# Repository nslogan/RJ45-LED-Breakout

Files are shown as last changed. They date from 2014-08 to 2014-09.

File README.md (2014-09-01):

# RJ45-LED-Breakout

## Description

Simple breakout board for an RJ45 with LEDs. Has two 0805 resistor pads tied to Vin with pins for LED1/2-. Has solder pads for both shield legs to optionally tie to ground. Intended for use with Amphenol RJHSE-548x series. You can find [this project on GitHub](https://github.com/nslogan/RJ45-LED-Breakout). Fits breadboard well with headers 0.9" apart.

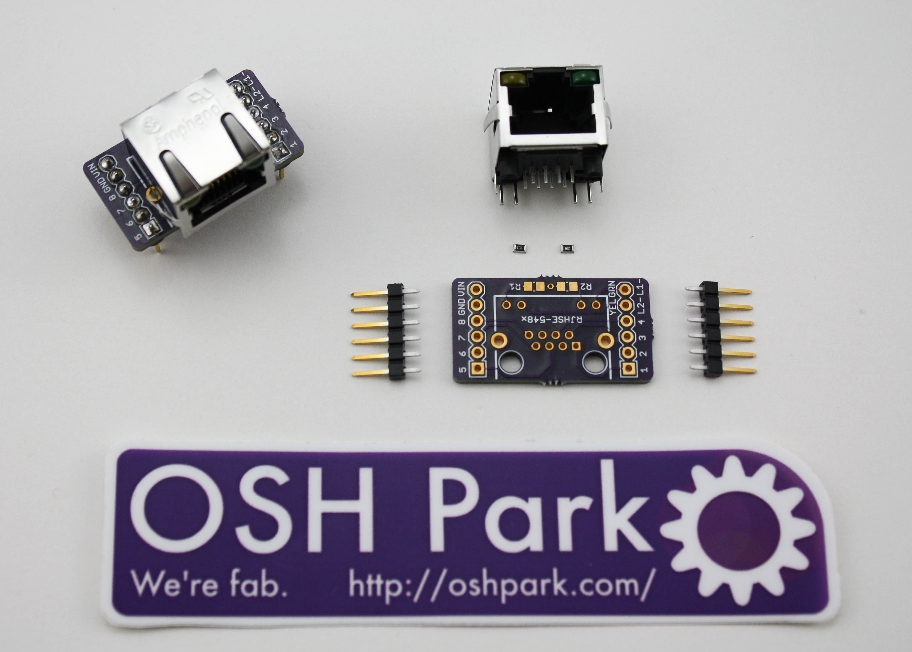
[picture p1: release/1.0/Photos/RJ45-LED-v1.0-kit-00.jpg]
RJ45-LED-Breakout Kit


## Production

The board measured 0.65x1.20in (17x30mm) and was designed for production at [OSH Park](https://www.oshpark.com/). The OSHPark DRU is located in the `res/` folder.

The boards can be purchased [here](https://www.oshpark.com/shared_projects/6Iadx5r2) @ $3.90 for three.

## Parts

All parts on this board are from the [LoganSmith-Eagle-Library](https://github.com/nslogan/LoganSmith-Eagle-Library) available on GitHub (work in progress).

The BOM is located in the release folder, all parts are sourced from Digi-Key.

## Project Structure

This project adheres to this structure:

	[ProjectName]
		README.md
		[release]
			[Major.Minor]
				ProjectName_BOM_Major.Minor.xls or ProjectName_BOM_BOM_Major.Minor.csv
				ProjectName_schematic_Major.Minor.pdf
				ProjectName_board-<top/mid#/bottom>_Major.Minor.png
				ProjectName_Major.Minor.sch
				ProjectName_Major.Minor.brd
				[Gerbers]
					...
			...
		[src]
			[Major.0]
				BoardName.sch
				BoardName.brd
				BOM.xls or BOM.csv
			[Major+1.0]
				...
			...
		[lib]
			...
		[res]
			Manufacturer.dru
			Manufacturer.cam

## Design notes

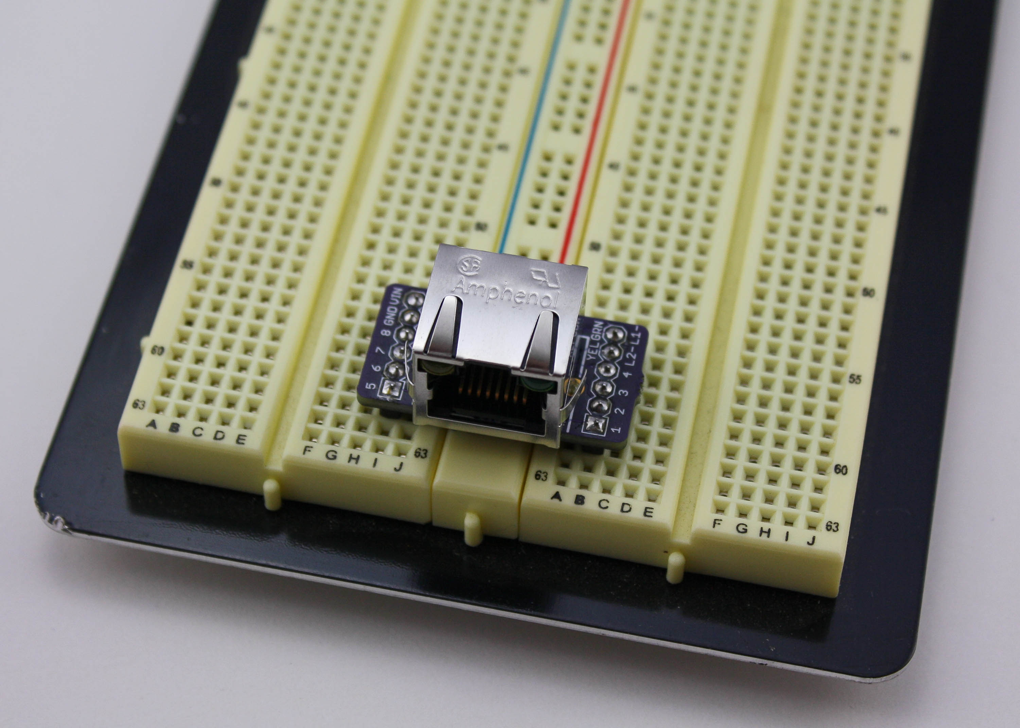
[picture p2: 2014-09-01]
release/1.0/Photos/RJ45-LED-v1.0-on-board-00.jpg

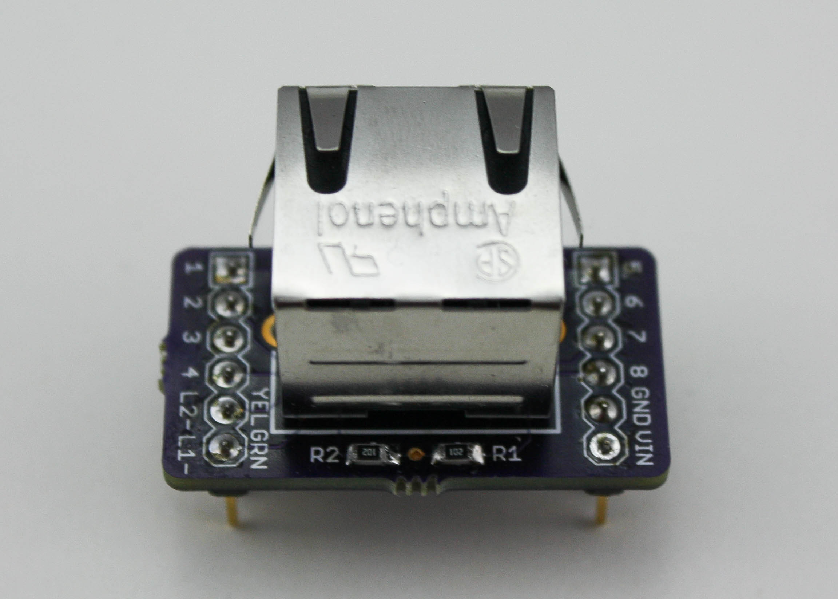
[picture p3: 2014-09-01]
release/1.0/Photos/RJ45-LED-v1.0-pop-top-00.jpg

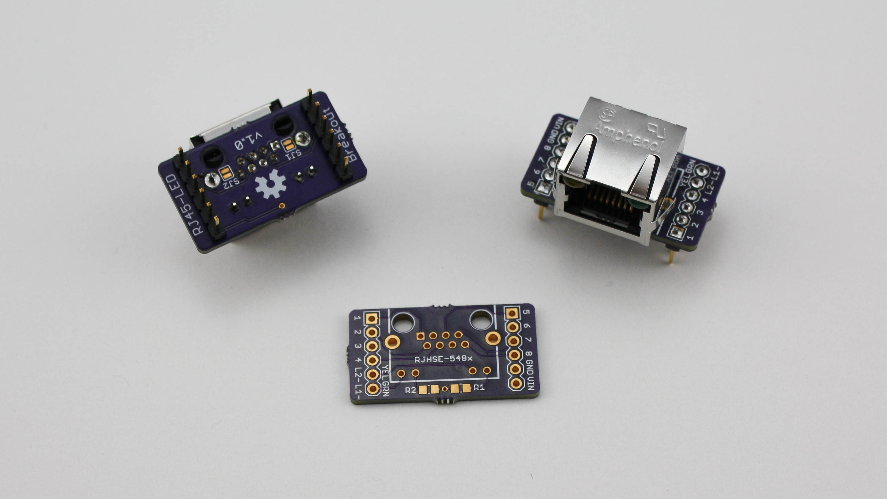
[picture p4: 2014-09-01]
release/1.0/Photos/RJ45-LED-v1.0-2pop-1upop-00.jpg

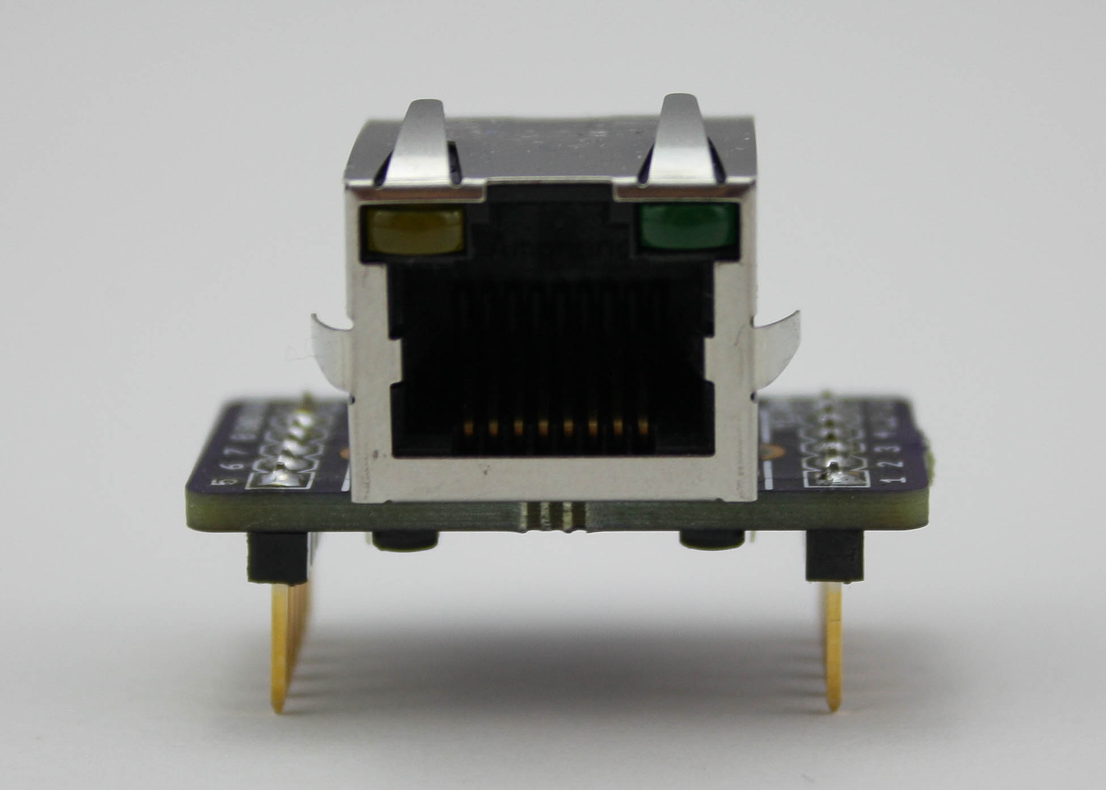
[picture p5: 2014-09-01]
release/1.0/Photos/RJ45-LED-v1.0-pop-front.jpg

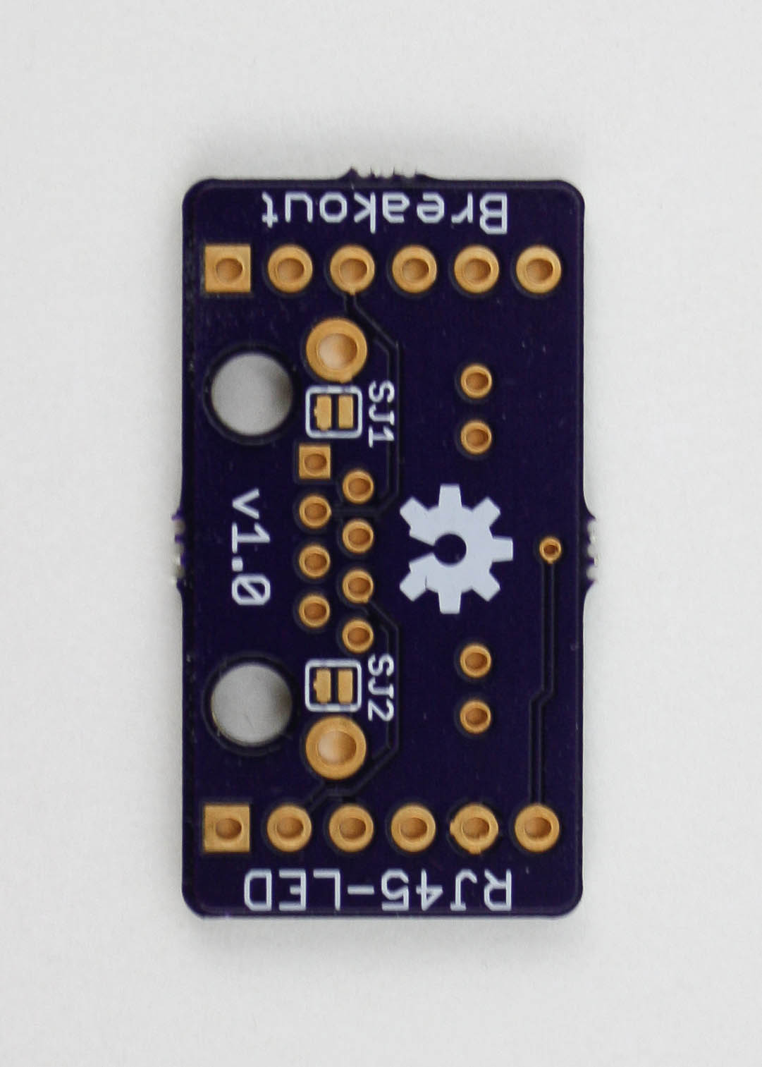
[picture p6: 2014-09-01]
release/1.0/Photos/RJ45-LED-v1.0-bottom.jpg

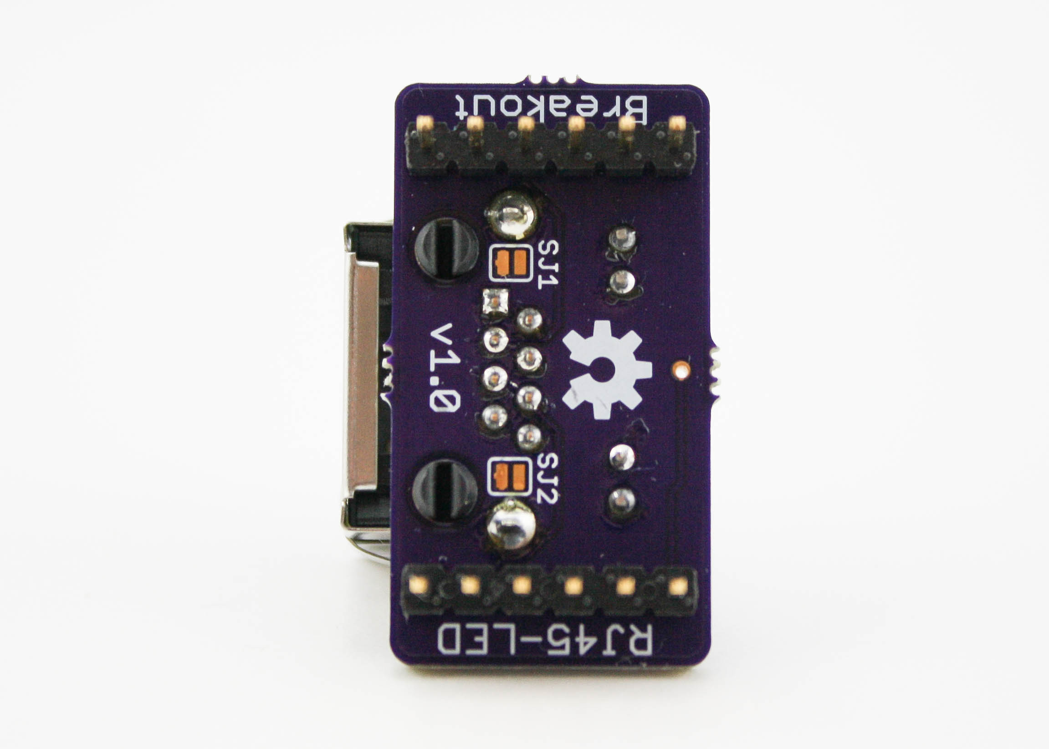
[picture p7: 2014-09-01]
release/1.0/Photos/RJ45-LED-v1.0-pop-bottom.jpg

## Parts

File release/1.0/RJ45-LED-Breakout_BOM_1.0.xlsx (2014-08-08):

Part | QTY | Package | Description | DIGIKEY_OC | MFR | MPN | TEMP_RANGE | THICK | VALUE
J1 | 1 | RJ45-RJHSE | Shielded CAT5 RJ45 90 w/ LED and board lock | RJHSE-5481-ND | Amphenol Commercial Products | RJHSE-5481 | -55C to 85C | 0.530in | RJ45
J2,J3 | 2 | 1x6 | 1x8 Headers Gold 15uin | 609-3256-ND | FCI | 68000-206HLF |  | 0.230in | 1x6
R1,R2 | 2 | 0805 | 1k 5% 0805 RES 0.125W | P1.0KACT-ND | Panasonic Electronic Components | ERJ-6GEYJ102V |  | 0.70mm | 1k

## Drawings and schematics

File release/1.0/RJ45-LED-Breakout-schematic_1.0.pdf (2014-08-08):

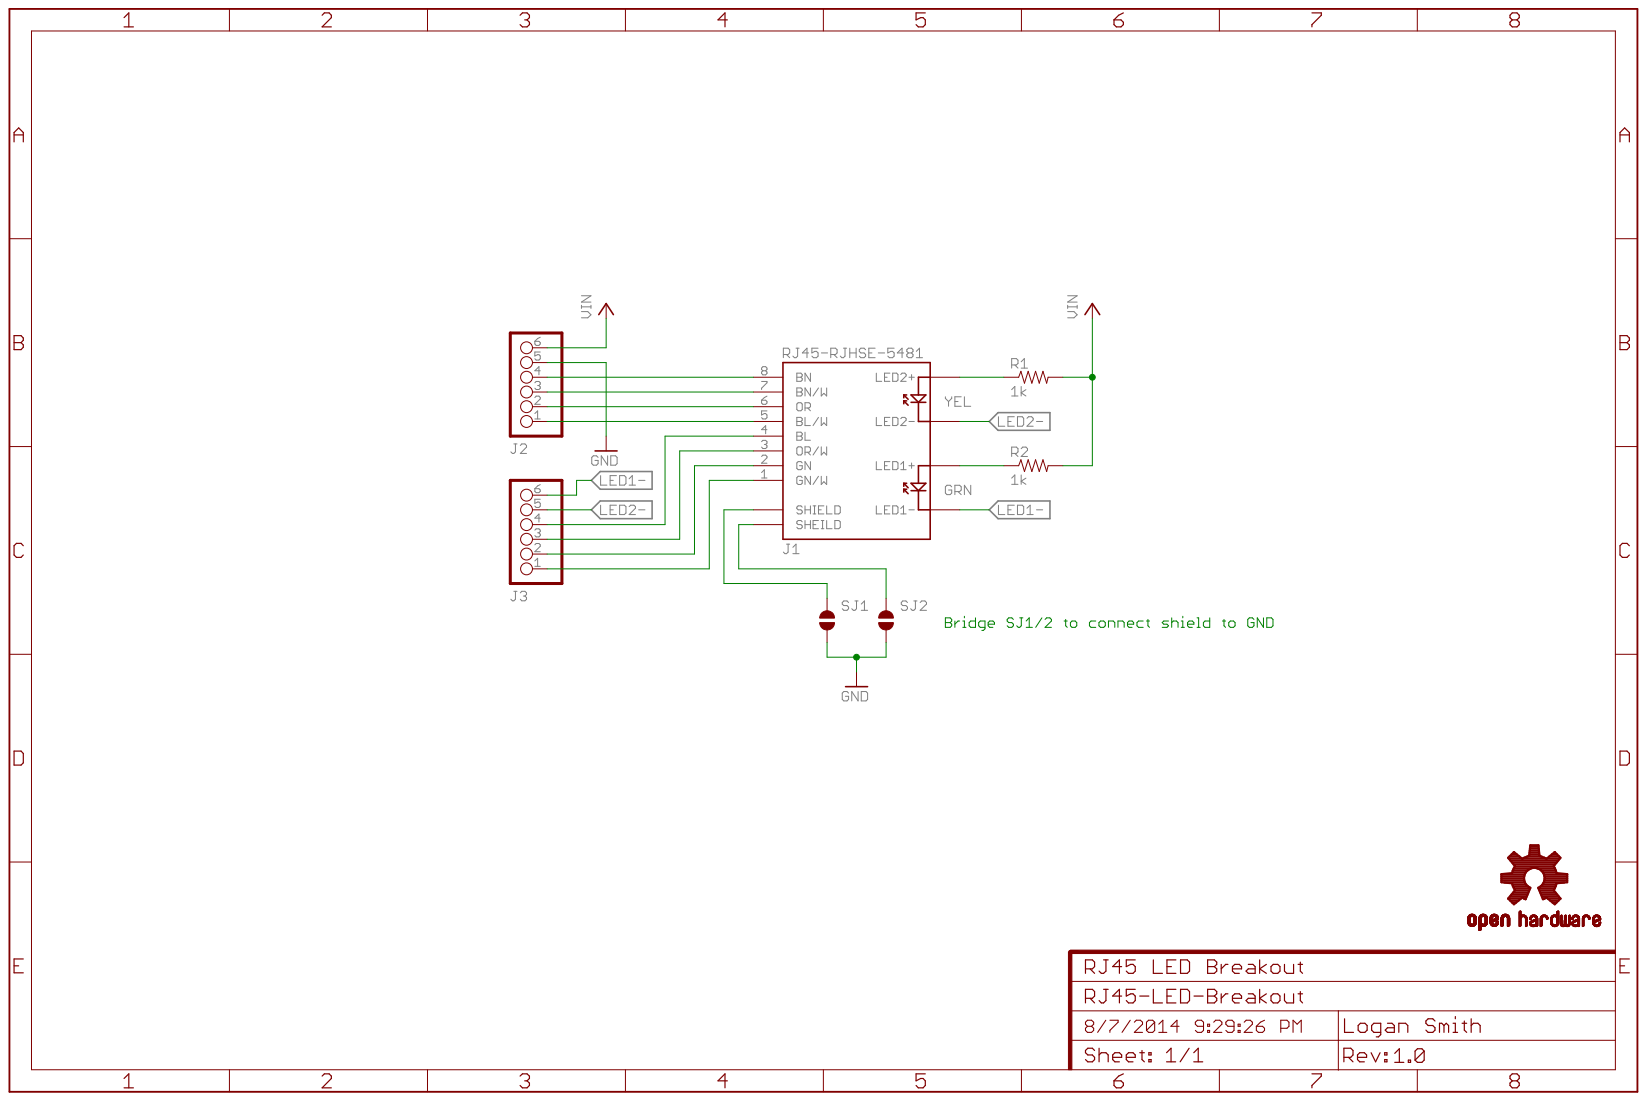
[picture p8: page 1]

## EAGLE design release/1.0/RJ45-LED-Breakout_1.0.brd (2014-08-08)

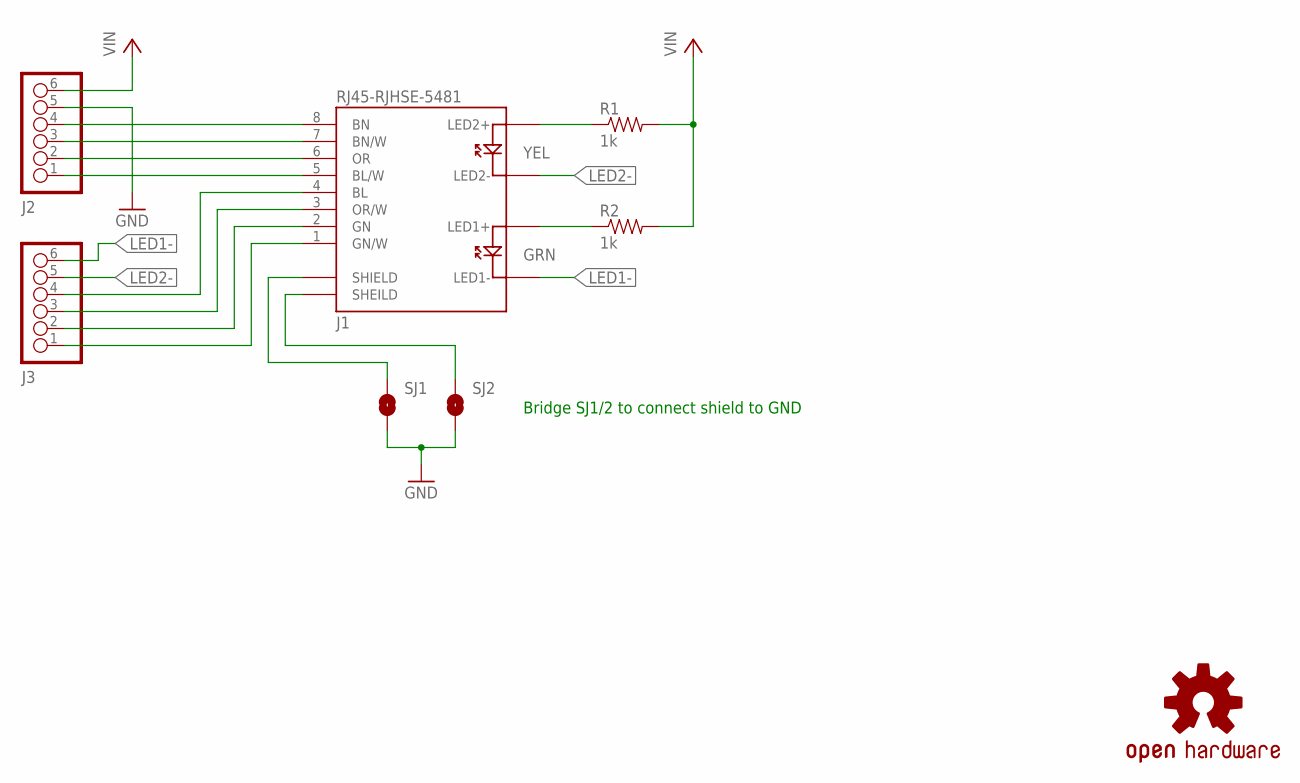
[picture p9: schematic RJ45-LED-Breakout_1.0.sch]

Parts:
J1: RJ45-RJHSE-5481; RJ45-RJHSE
J2, J3: M06SQ1; 1X06_SQ1
LOGO1: OSHW-LOGOM; OSHW-LOGO-M
R1, R2: 1k; 0805-RES
SJ1, SJ2: SJ_1WAY; SJ_2

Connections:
GND: J2.5, SJ1.2, SJ2.2
LED1+: J1.LED1+, R2.P$1 (1)
LED1-: J1.LE1D- (LED1-), J3.6
LED2+: J1.LED2+, R1.P$1 (1)
LED2-: J1.LED2-, J3.5
unnamed: J1.5 (BL/W), J2.1
unnamed: J1.6 (OR), J2.2
unnamed: J1.7 (BN/W), J2.3
unnamed: J1.8 (BN), J2.4
unnamed: J1.4 (BL), J3.4
unnamed: J1.3 (OR/W), J3.3
unnamed: J1.2 (GN), J3.2
unnamed: J1.1 (GN/W), J3.1
unnamed: J1.SHIELD@0 (SHIELD), SJ1.1
unnamed: J1.SHEILD@1 (SHEILD), SJ2.1
VIN: J2.6, R1.P$2 (2), R2.P$2 (2)

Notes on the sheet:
Bridge SJ1/2 to connect shield to GND

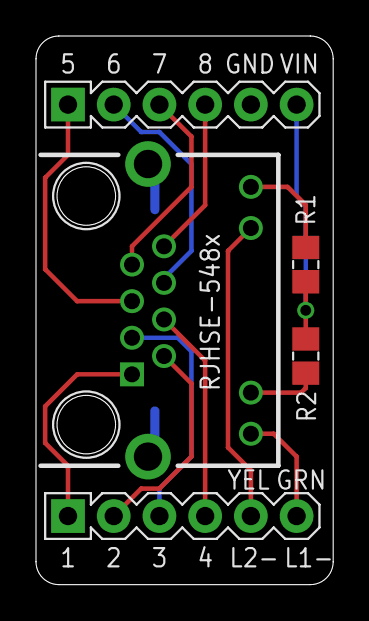
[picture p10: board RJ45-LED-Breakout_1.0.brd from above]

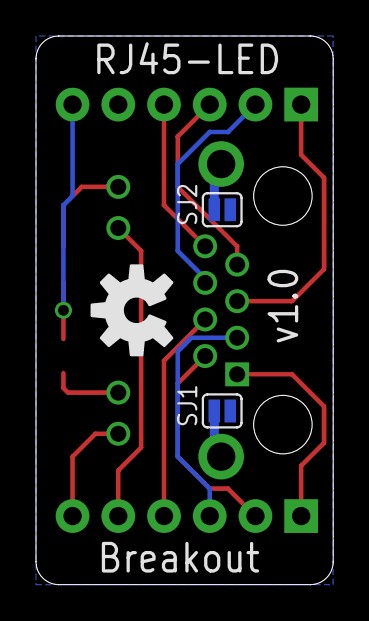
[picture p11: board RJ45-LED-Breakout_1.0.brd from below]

Board: 2 copper layers, 16.5 x 30.5 mm, 8 parts (3 on the bottom side), 16 nets.

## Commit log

2014-08-07 Initial commit. Need to add solder jumper to connect shield and ground (normally open) and lay out board. May move some of the pins around depending on how the layout goes.
    [RJ45-LED-Breakout.brd, RJ45-LED-Breakout.sch]
2014-08-07 Switching to develop branch.
    [RJ45-LED-Breakout.brd]
2014-08-07 Board mostly laid out but pins 7/8 are switched. Fix that then reroute and it is basicaly done. Need to add some more info on silk.
    [RJ45-LED-Breakout.brd, RJ45-LED-Breakout.sch]
2014-08-07 Almost ready for release. Need to create BOM and review all connections. Also look over schematic and possibly clean things up if necessary.
    [RJ45-LED-Breakout.brd, RJ45-LED-Breakout.sch]
2014-08-08 Board has been ordered. Updated README, finalized board layout and silk. Need to create BOM and release 1.0.
    [RJ45-LED-Breakout.brd, RJ45-LED-Breakout.sch]
2014-08-08 Release 1.0 ready to go, gonna double check a few things and merge to master.
    [BOM.xlsx, RJ45-LED-Breakout_1.0.brd, RJ45-LED-Breakout_1.0.sch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]

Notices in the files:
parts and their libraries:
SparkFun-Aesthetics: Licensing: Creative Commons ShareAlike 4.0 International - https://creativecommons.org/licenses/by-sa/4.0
